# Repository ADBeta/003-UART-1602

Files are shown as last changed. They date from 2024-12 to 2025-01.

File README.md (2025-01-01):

# 003-UART-1602
UART/RS232 Enabled controller for a basic `1602 Monochrome LCD`, in 4-bit mode
using the `CH32V003 - TSSOP-20` MCU  
Features:
* Selectable Baudrate
* Backlight Control using UART or Hardware override
* 4-bit LCD Control protocol support
* Automatic Line Scroll
* Operation down to 2.7v
* LCD Contrast Charge Pump
* Advance Display Control over UART

<div style="display: flex; align-items: center; gap: 10px;">
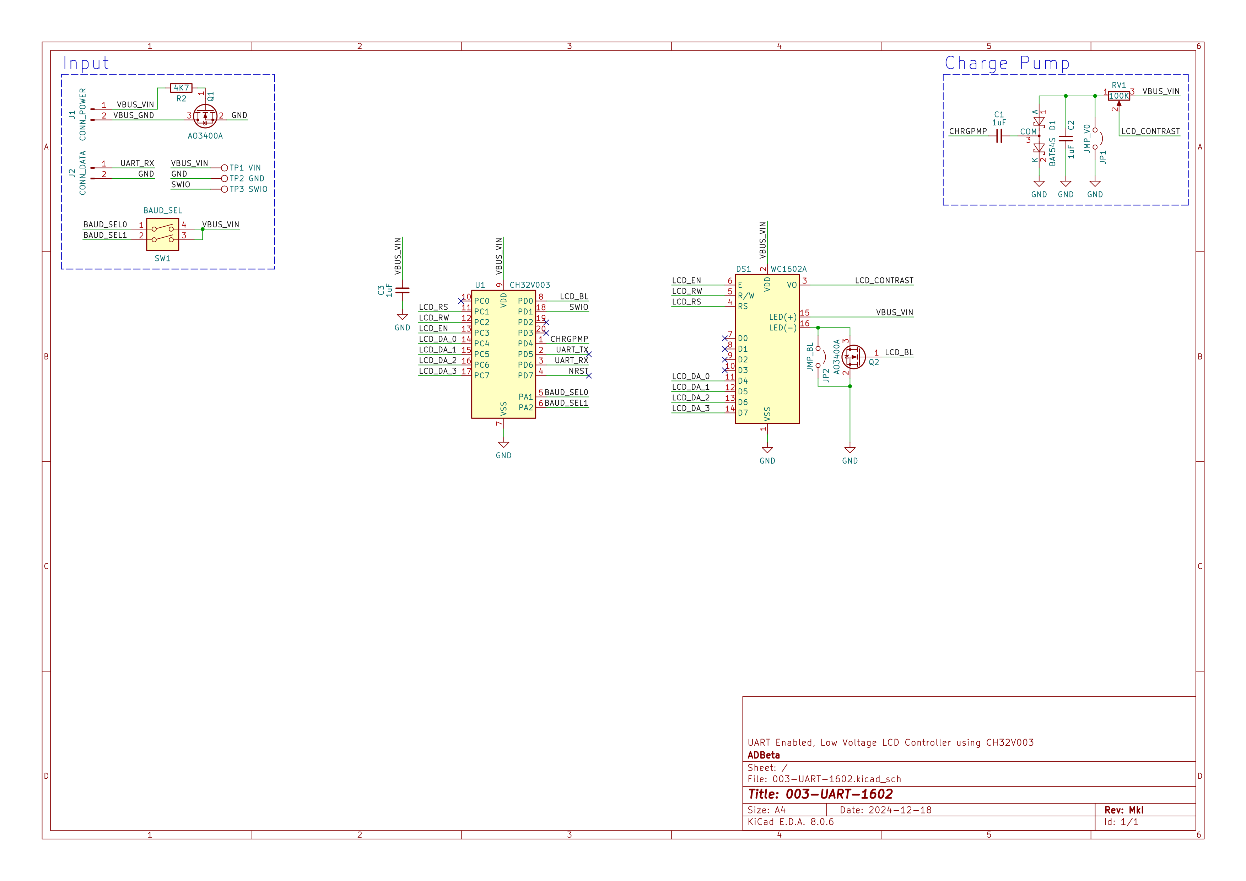
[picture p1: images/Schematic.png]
Schematic
  <br>
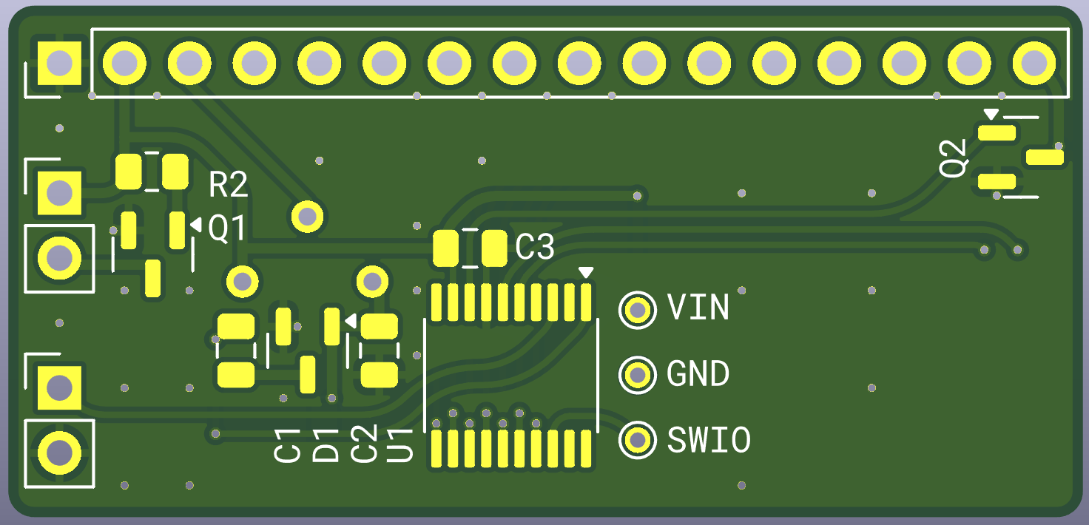
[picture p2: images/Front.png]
PCB_Front
  
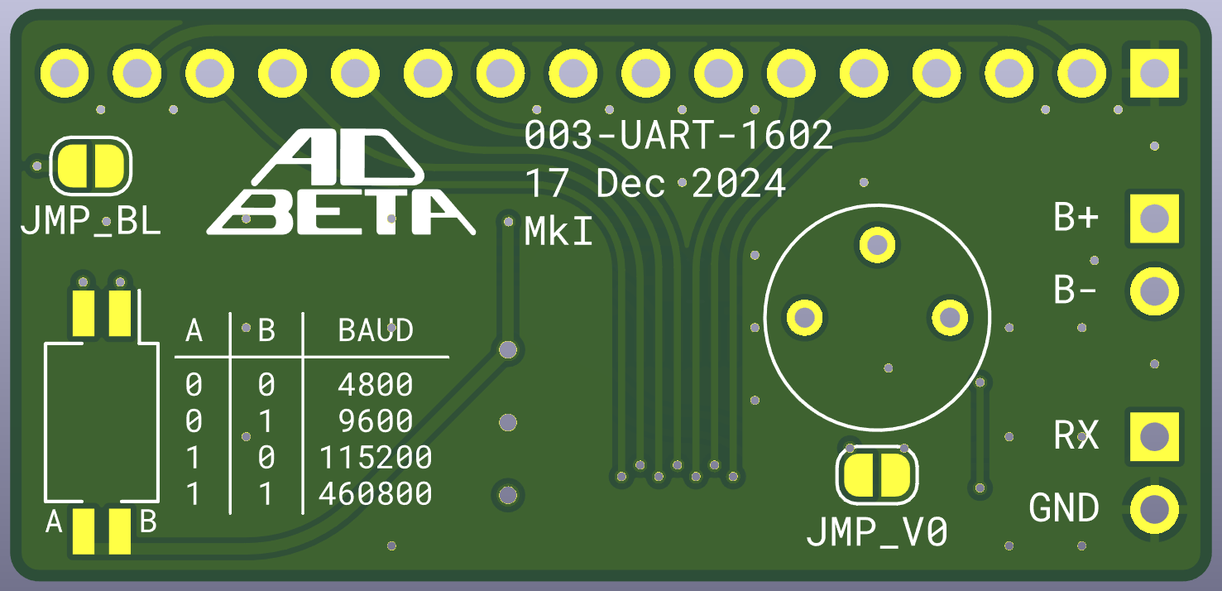
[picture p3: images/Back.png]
PCB_Back
  
</div>

## Display Operation
The display will read any incoming UART or RS232 Data and print it to the 
screen in realtime - If the edge of the screen is exceeded, the display will
drop incoming data.  
When `Line Feed` is received, and the Display is already on `Line 2`, the display
will Scroll Down, so the line being printed to remains as `Line 2`  

See [Control Characters](#control-characters) for a list of control commands
that can be used for the display

## Startup Conditions
When the Display is powered on, and before it receives any UART data, the
device is in the following state:
* LCB Backlight OFF
* Display Configured and blanked

## Selectable Baudrate
Receiver Baudrate is selected via the DIP-Switches onboard.  
The setting is checked once a second so the setting can be 
changed on the fly.  
```
B1 B0  Baud
0  0   4800
0  1   9600
1  0   115200
1  1   460800
```

## Low Voltage Operation
There is a negative charge pump onboard that provides a near-rail negative
voltage, that is fed to one end of the contrast selection Potentiometer.  
These LCDs are only officially rated at 5v, so use lower voltages 
**AT  YOUR OWN RISK**.  
To disable the charge pump, do not populate the components, and short
the `JMP_V0` Jumper.  
The `Minimum Voltage` for the unit is 2.7v

## Control Characters
`BELL    0x07` - Flashes the Backlight quickly for 3 Seconds  
`LF      0x0A` - Feeds line down, keeping Column Position  
`CR      0x0D` - Returns to the First Column on the current line  
`DC1     0x11` - Device Control 1, Turns Backlight On  
`DC2     0x12` - Device Control 2, Turns Backlight Off  
`DC3     0x13` -   
`DC4     0x14` -  
`ESCAPE  0x1B` - Clears the Screen and returns to position 0,0  

Any Control Characters not mentioned above will be ignored.

## Pinout
```
PA1  Baud Select 1
PA2  Baud Select 2

PC0  ---
PC1  LCD_RS  Register Select
PC2  LCD_RW  Read/Write
PC3  LCD_EN  Enable
PC4  LCD_D4  Display Data Pin 4
PC5  LCD_D5  Display Data Pin 5
PC6  LCD_D6  Display Data Pin 6
PC7  LCD_D7  Display Data Pin 7

PD0  Backlight Control
PD1  !!Reserved for SWIO!!
PD2  --
PD3  --
PD4  Charge Pump PWM
PD5  TX  UART Transmit (Not Connected)
PD6  RX  UART Receive
PD7  Reserved for NRST
```

## MkII PCB Partslist
```
C1    0603 1uF 10V
C2    0603 1uF 10V
C3    0603 1uF 10V
R1    0603 4K7
R2    100K 5mm x 5mm Potentiometer
D1    BAT54S
Q1    AO3401 P-Ch
Q2    A03400 N-Ch
U1    CH32V003
SW1   1.27mm 2P DIP Switch
```

## TODO
* Device Contol 3 and 4 Behaviour

----
ADBeta (c) 2024 - 2025

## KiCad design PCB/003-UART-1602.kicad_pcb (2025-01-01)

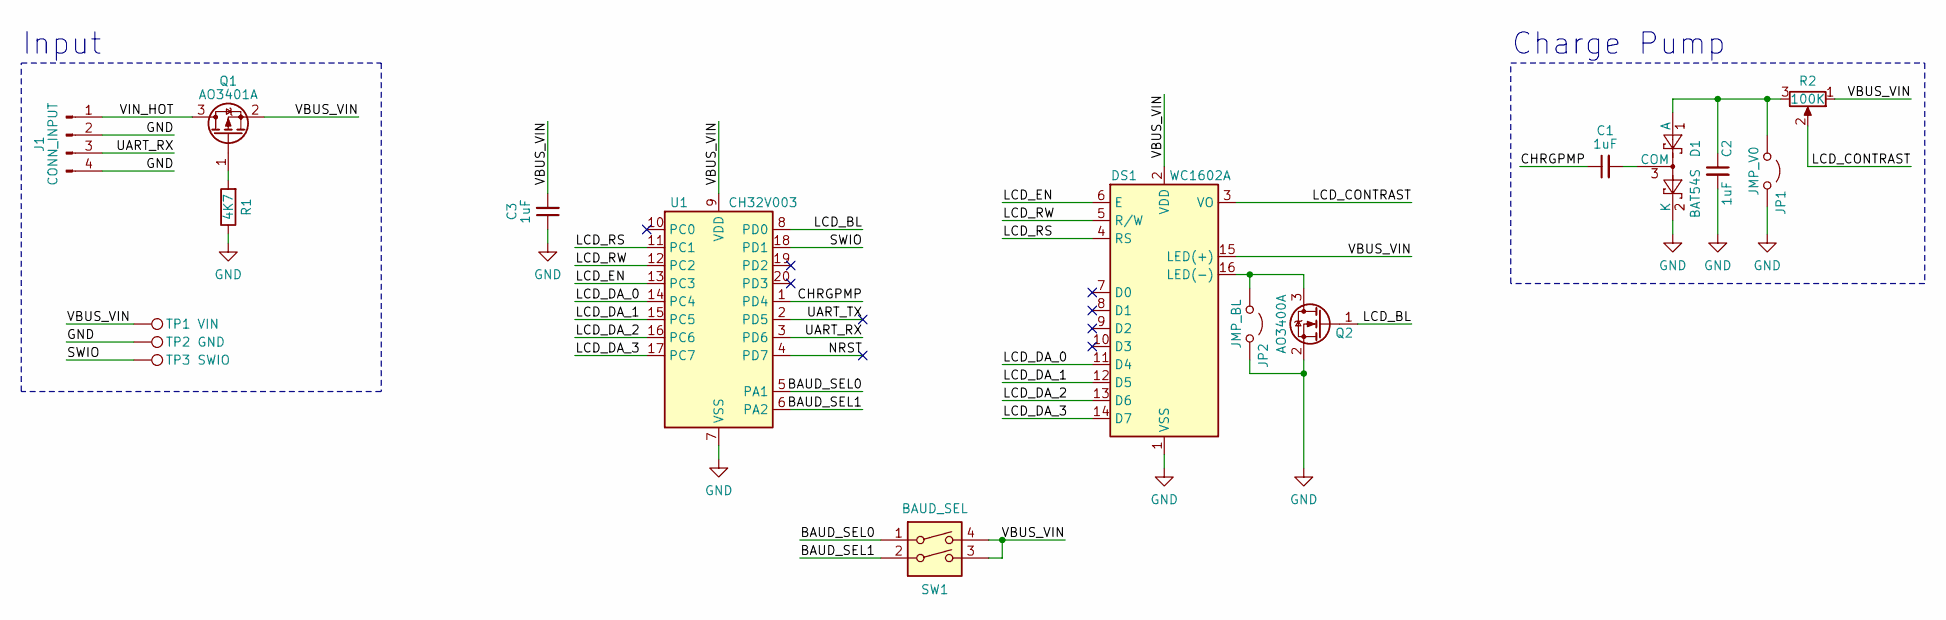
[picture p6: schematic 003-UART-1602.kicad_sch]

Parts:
C1, C2, C3: 1uF; C_0805_2012Metric
D1: BAT54S; SOT-23
DS1: WC1602A; PinHeader_1x16_P2.54mm_Vertical
J1: CONN_INPUT; PinHeader_1x04_P2.54mm_Vertical
JP1: JMP_V0; SolderJumper-2_P1.3mm_Open_RoundedPad1.0x1.5mm
JP2: JMP_BL; SolderJumper-2_P1.3mm_Open_RoundedPad1.0x1.5mm
Q1: AO3401A; SOT-23
Q2: AO3400A; SOT-23
R1: 4K7; R_0805_2012Metric
R2: 100K; Potentiometer_Piher_PT-6-V_Vertical
SW1: BAUD_SEL; SW_DIP_SPSTx02_Slide_Copal_CHS-02B_W7.62mm_P1.27mm
TP1: VIN; TestPoint_Pad_D1.0mm
TP2: GND; TestPoint_Pad_D1.0mm
TP3: SWIO; TestPoint_Pad_D1.0mm
U1: CH32V003; TSSOP-20_4.4x6.5mm_P0.65mm

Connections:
/BAUD_SEL0: SW1.1, U1.5 (PA1)
/BAUD_SEL1: SW1.2, U1.6 (PA2)
/CHRGPMP: C1.1, U1.1 (PD4)
/LCD_BL: Q2.1 (G), U1.8 (PD0)
/LCD_CONTRAST: DS1.3 (VO), R2.2
/LCD_DA_0: DS1.11 (D4), U1.14 (PC4)
/LCD_DA_1: DS1.12 (D5), U1.15 (PC5)
/LCD_DA_2: DS1.13 (D6), U1.16 (PC6)
/LCD_DA_3: DS1.14 (D7), U1.17 (PC7)
/LCD_EN: DS1.6 (E), U1.13 (PC3)
/LCD_RS: DS1.4 (RS), U1.11 (PC1)
/LCD_RW: DS1.5 (R/W), U1.12 (PC2)
/NRST: U1.4 (PD7)
/SWIO: TP3.1, U1.18 (PD1)
/UART_RX: J1.3, U1.3 (PD6)
/UART_TX: U1.2 (PD5)
/VBUS_VIN: C3.2, DS1.2 (VDD), DS1.15 (LED(+)), Q1.2 (S), R2.1, SW1.3, SW1.4, TP1.1, U1.9 (VDD)
/VIN_HOT: J1.1, Q1.3 (D)
GND: C2.2, C3.1, D1.2 (K), DS1.1 (VSS), J1.2, J1.4, JP1.1 (A), JP2.1 (A), Q2.2 (S), R1.1, TP2.1, U1.7 (VSS)
unnamed: C2.1, D1.1 (A), JP1.2 (B), R2.3
unnamed: C1.2, D1.3 (COM)
unnamed: DS1.16 (LED(-)), JP2.2 (B), Q2.3 (D)
unnamed: Q1.1 (G), R1.2

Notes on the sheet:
Charge Pump
Input

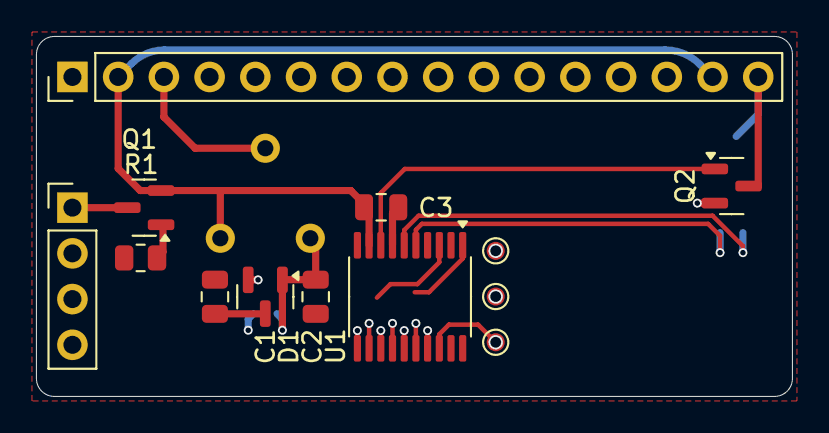
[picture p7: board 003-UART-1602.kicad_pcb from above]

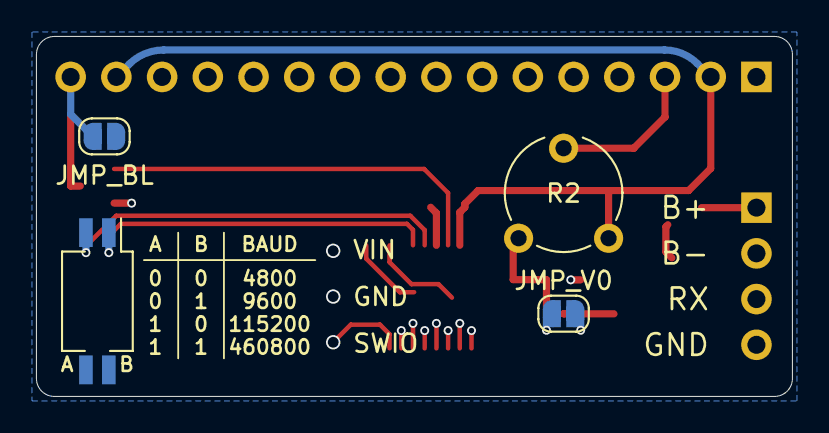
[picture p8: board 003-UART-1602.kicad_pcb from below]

Board: 2 copper layers, 42.0 x 20.0 mm, 17 parts (4 on the bottom side), 21 nets.

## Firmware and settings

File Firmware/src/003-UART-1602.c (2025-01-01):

/******************************************************************************
* 003-UART-1602
* A UART Enabled Controller for a basic 1602 Monochrome LCD
* For more information see the GitHub: 
* https://github.com/ADBeta/003-UART-1602
*
* Ver 1.4    01 Jan 2025
* ADBeta (c) 2024 - 2025
******************************************************************************/
#include "ch32v003fun.h"
#include "lib_gpioctrl.h"
#include "lib_uart.h"
#include "lib_lcd1602.h"

/*** Pin Definitions *********************************************************/
#define PUMP_PWM     GPIO_PD4
#define LCD_BL       GPIO_PD0
#define BAUD_SEL0    GPIO_PA1
#define BAUD_SEL1    GPIO_PA2

/*** Macros ******************************************************************/
#define SYSTICK_ONE_MILLISECOND ((uint32_t)FUNCONF_SYSTEM_CORE_CLOCK / 1000)
#define SYSTICK_ONE_MICROSECOND ((uint32_t)FUNCONF_SYSTEM_CORE_CLOCK / 1000000)
#define millis() (g_systick_millis)
#define micros() (SysTick->CNT / SYSTICK_ONE_MICROSECOND)

/*** Enums and Structs *******************************************************/
typedef enum {
	LED_OFF       = 1,
	LED_ON        = 2,
	LED_BLINK     = 3
} led_mode_t;


/*** Globals *****************************************************************/
//// UART ////
// UART Ring Buffer and Receive buffer
#define UART_BUFFER_SIZE 128
static uint8_t g_uart_buffer[UART_BUFFER_SIZE] = {0x00};
static uint8_t g_recv_buffer[UART_BUFFER_SIZE] = {0x00};

// Baudrate lookup table
static uart_baudrate_t g_baud_lookup[4] = { 
	UART_BAUD_4800, UART_BAUD_9600, UART_BAUD_115200, UART_BAUD_460800 
};

// Create a UART Configuration 
static uart_config_t g_uart_conf = {
	.baudrate    = UART_BAUD_4800,
	.wordlength  = UART_WORDLENGTH_8,
	.parity      = UART_PARITY_NONE,
	.stopbits    = UART_STOPBITS_ONE,
	.flowctrl    = UART_FLOWCTRL_NONE,
};

//// LCD ////
#define LCD_LINE_MAX_CHARS 16

// Create LCD Device
static lcd_device_t g_lcd_dev = {
	.LCD_RS      = GPIO_PC1,
	.LCD_RW      = GPIO_PC2,
	.LCD_EN      = GPIO_PC3,
	.LCD_DA      = {GPIO_PC4, GPIO_PC5, GPIO_PC6, GPIO_PC7},
};

lcd_position_t g_lcd_pos = {0, 0};

// When a BELL is received, blink a set number of times.
led_mode_t g_led_mode =   LED_OFF;
uint32_t   g_led_blinks = 0;


//// Timing ////
// Incremented in the SysTick IRQ once per millisecond
volatile uint32_t g_systick_millis;

#define BAUD_UPDATE_MS   1000
#define DISP_UPDATE_MS     50
#define LIGHT_UPDATE_MS   100

static uint32_t g_last_baud_update_millis    = 0;
static uint32_t g_last_disp_update_millis    = 0;
static uint32_t g_last_light_update_millis   = 0;


/*** Forward Declaration *****************************************************/
/// @brief Initialise the SysTick interrupt to incriment every 1 millisecond
/// @param None
/// @return None
static void systick_init(void);

/// @brief SysTick IRQ
/// @param none
/// @return none
__attribute__((interrupt))
void SysTick_Handler(void);

/// @brief Initialises PWM on Timer2,         NOTE: PD4 in this case
/// @param None
/// @return None
void pwm_init(void);

/// @brief Sets the Duty Cycle PWM output
/// @param duty, 0 - 255
/// @return None
__attribute__((always_inline))
inline void pwm_set_duty(const uint32_t duty);

/// @brief returns if the given char is a printable char
/// @param char input
/// @return bool result
__attribute__((always_inline))
inline bool is_printable(const char input) {
	if(input >= 0x20) return true;
	return false;
}



/*** Main ********************************************************************/
int main(void)
{	
	/*** Init ***/
	SystemInit();

	// Backlight is output, turn off by default
	gpio_set_mode(LCD_BL, OUTPUT_10MHZ_PP);
	gpio_digital_write(LCD_BL, GPIO_LOW);
	// Selection Switches are input
	gpio_set_mode(BAUD_SEL0, INPUT_PULLDOWN);
	gpio_set_mode(BAUD_SEL1, INPUT_PULLDOWN);
	// Charge Pump is output in alternate function mode for PWM
	gpio_set_mode(PUMP_PWM, OUTPUT_10MHZ_PP | OUTPUT_PP_AF);

	// Wait for power to settle then init LCD
	Delay_Ms(250);
	lcd_init(&g_lcd_dev);

	// Start the PWM on PD4: 50% Duty, 9.9KHz
	pwm_init();
	pwm_set_duty(127);

	// Enable the systick for timing update and read of user settings
	systick_init();
	
	// Initialise the UART driver, will start populating ring buffer
	uart_init(g_uart_buffer, UART_BUFFER_SIZE, &g_uart_conf);



	/*** Main Loop ***/
	while(true)
	{
		/*** Baudrate Selection Switch ***/
		if(g_systick_millis - g_last_baud_update_millis > BAUD_UPDATE_MS)
		{
			// Get the current Baud Setting selection
			uint8_t baud_setting = 
				((uint8_t)gpio_digital_read(BAUD_SEL1)) << 1 |
				 (uint8_t)gpio_digital_read(BAUD_SEL0);

			// Set the Baudrate register
			USART1->BRR = g_baud_lookup[baud_setting];

			// Reset for the next baudrate update
			g_last_baud_update_millis = g_systick_millis;
		} // End of Baudrate Selection



		/*** UART Data Parsing ***/
		if(g_systick_millis - g_last_disp_update_millis > DISP_UPDATE_MS)
		{
			// Read any bytes availabe in the buffer, then parse it 
			size_t recv_chars = uart_read(g_recv_buffer, UART_BUFFER_SIZE);

			// Go through every received char to parse it
			for(uint8_t index = 0; index < recv_chars; index++)
			{
				char c_char = g_recv_buffer[index];
				

				// Print only Printable characters
				if(is_printable(c_char))
				{
					// Get the current position, only print if below x[16]
					g_lcd_pos = lcd_get_pos(&g_lcd_dev);
					if(g_lcd_pos.x < 16) 
						lcd_send_char(&g_lcd_dev, c_char);

				// If it is a control char, parse it
				} else {
					switch(c_char)
					{
						// BELL
						case 0x07:
							g_led_mode = LED_BLINK;
							g_led_blinks = 20;
							break;

						// LINE FEED
						// Moves down one line, keeping carriage position.
						// If on line 2, move display info up to line 1
						case 0x0A:
							// Get the current position, if on the 1st line, move down
							g_lcd_pos = lcd_get_pos(&g_lcd_dev);
							if(g_lcd_pos.y == 0)
							{
								g_lcd_pos.y = 1;
								lcd_set_pos(&g_lcd_dev, g_lcd_pos);
							
							// If it's on the second line...
							} else {
								// Copy line 2 data to buffer
								char line_str[17] = {0x00};
								lcd_set_pos(&g_lcd_dev, (lcd_position_t){0,1});
								lcd_read_string(&g_lcd_dev, line_str, 16);

								// Clear display - resets to 0,0
								// write line 2 data to line 1
								lcd_send_cmd(&g_lcd_dev, 0x01);
								lcd_send_string(&g_lcd_dev, line_str);

								// Set the position to where it was
								lcd_set_pos(&g_lcd_dev, g_lcd_pos);
							}							
							break;

						// CARRIAGE RETURN
						// Sets cursor position to char 0 of the current line
						case 0x0D:
							g_lcd_pos = lcd_get_pos(&g_lcd_dev);
							g_lcd_pos.x = 0;
							lcd_set_pos(&g_lcd_dev, g_lcd_pos);
							break;

						// DEVICE CONTROL 1
						// Backlight ON
						case 0x11:
							g_led_mode = LED_ON;
							g_led_blinks = 0;
							break;

						// DEVICE CONTROL 2
						// Backlight OFF
						case 0x12:
							g_led_mode = LED_OFF;
							g_led_blinks = 0;
							break;
					
						// DEVICE CONTROL 3
						// TBD
						case 0x13:
							break;
					
						// DEVICE CONTROL 4
						// TBD
						case 0x14:
							break;

						// ESCAPE
						// Clears the display and returns to 0
						case 0x1B:
							lcd_send_cmd(&g_lcd_dev, 0x01);
							break;

						default:
							break;
					}
				}
			}


			// Reset timer for next UART Data Update
			g_last_disp_update_millis = g_systick_millis;
		} // End of Character Parsing



		if(g_systick_millis - g_last_light_update_millis > LIGHT_UPDATE_MS)
		{
			static led_mode_t last_mode = LED_OFF;
			static GPIO_STATE last_state = GPIO_LOW;


			switch(g_led_mode)
			{
				case LED_OFF:
					gpio_digital_write(LCD_BL, GPIO_LOW);
					last_mode =   LED_OFF;
					last_state =  GPIO_LOW;
					break;

				case LED_ON:
					gpio_digital_write(LCD_BL, GPIO_HIGH);
					last_mode =   LED_ON;
					last_state =  GPIO_HIGH;
					break;

				case LED_BLINK:
					// Reset when done blinking
					if(g_led_blinks-- == 0) g_led_mode = last_mode;
					// Toggle the LED
					gpio_digital_write(LCD_BL, (last_state = !last_state));
					
					break;
				

				default:
					break;
			}

			g_last_light_update_millis = g_systick_millis;
		} // End of Backlight Update

	} // End of loop
} // End of main()




/*** Functions ***************************************************************/
static void systick_init(void)
{
	// Reset any pre-existing configuration
	SysTick->CTLR = 0x0000;
	
	// Set the compare register to trigger once per millisecond
	SysTick->CMP = SYSTICK_ONE_MILLISECOND - 1;

	// Reset the Count Register, and the global millis counter to 0
	SysTick->CNT = 0x00000000;
	g_systick_millis = 0x00000000;
	
	// Set the SysTick Configuration
	// NOTE: By not setting SYSTICK_CTLR_STRE, we maintain compatibility with
	// busywait delay funtions used by ch32v003_fun.
	SysTick->CTLR |= SYSTICK_CTLR_STE   |  // Enable Counter
	                 SYSTICK_CTLR_STIE  |  // Enable Interrupts
	                 SYSTICK_CTLR_STCLK ;  // Set Clock Source to HCLK/1
	
	// Enable the SysTick IRQ
	NVIC_EnableIRQ(SysTicK_IRQn);
}


__attribute__((interrupt))
void SysTick_Handler(void)
{
	// Increment the Compare Register for the next trigger
	SysTick->CMP += SYSTICK_ONE_MILLISECOND;

	// Clear the trigger state for the next IRQ
	SysTick->SR = 0x00000000;

	// Increment the milliseconds count
	g_systick_millis++;
}


void pwm_init(void)
{
	// NOTE: Uses TIM2 Channel 1 (PD0) as the PWM Output pin
	// Change CHCTLR1 to CHCTLR2 for CH3 or CH4

	// Enable TIM2 Clock
	RCC->APB1PCENR |= RCC_APB1Periph_TIM2;
	
	// Reset TIM2, Inits all registers
	RCC->APB1PRSTR |= RCC_APB1Periph_TIM2;
	RCC->APB1PRSTR &= ~RCC_APB1Periph_TIM2;

	// Set Prescaler (9.9kHz)
	TIM2->PSC = 0x0012;
	// Set PWM Max Value (Autoreload Value)
	TIM2->ATRLR = 254;

	// Set the Compare Capture Register for Channel 1
	// TIM2_OC1M = 0b111 - PWM Mode 2 - Enable Preload
	TIM2->CHCTLR1 |= TIM_OC1M_2 | TIM_OC1M_1 | TIM_OC1M_0 | TIM_OC1PE;

	// Enable auto-reload
	TIM2->CTLR1 |= TIM_ARPE;

	// Enable channel output, set polarity ACTIVE_LOW
	TIM2->CCER |= TIM_CC1E | TIM_CC1P;

	// Initialise Counter
	TIM2->SWEVGR |= TIM_UG;

	// Enable TIM2
	TIM2->CTLR1 |= TIM_CEN;
}


__attribute__((always_inline))
inline void pwm_set_duty(const uint32_t duty)
{
	// NOTE: Channel 1, change CHxCVR for channel selection
	TIM2->CH1CVR = duty;
}

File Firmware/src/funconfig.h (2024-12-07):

#ifndef _FUNCONFIG_H
#define _FUNCONFIG_H

#define CH32V003                 1

// Enable/Disable overwriting of the RX Ring Buffer.
// Enabled:  Incomming data will overwrite older data in the buffer
// Disabled: Incomming data will not be added to the buffer until space is free
#define RX_RING_BUFFER_OVERWRITE

// NOTE: UART_ALTERNATE_1 will disable SWIO (PD1)
//  Pinout        TX        RX        CTS        RTS
//  Default       PD5       PD6       PD3        PC2
//  Alternate 1   PD0       PD1       PC3        PC2
//  Alternate 2   PD6       PD5       PC6        PC7
//  Alternate 3   PC0       PC1       PC6        PC7
#define UART_PINOUT_DEFAULT

#endif

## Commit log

2024-12-07 Added Basic UART Control
2024-12-07 Updated UART Code
2024-12-09 Added BAUD Setting detection
    [UART_LCD_MkI.kicad_sch]
2024-12-10 Added reverse protection to test & connectors
    [UART_LCD_MkI.kicad_sch]
2024-12-11 Changed parsing flow
2024-12-12 Fixed baud detection - Added Read CHAR from LCD Memory
    [UART_LCD.c, lib_lcd1602.c]
2024-12-12 Updated PCB
    [UART_LCD_MkI.kicad_pcb, UART_LCD_MkI.kicad_sch]
2024-12-16 PCB Progress
    [UART_LCD_MkI.kicad_pcb, UART_LCD_MkI.kicad_sch]
2024-12-16 Changed Project Name
    [003-UART-1602.kicad_pcb, 003-UART-1602.kicad_sch]
2024-12-17 Added DIP Switch to PCB
    [003-UART-1602.kicad_pcb, 003-UART-1602.kicad_sch]
2024-12-17 Almost Final PCB
    [003-UART-1602-B_Cu.gbr, 003-UART-1602-B_Mask.gbr, 003-UART-1602-B_Paste.gbr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]
2024-12-18 PCB Finished
    [003-UART-1602-B_Cu.gbr, 003-UART-1602-B_Mask.gbr, 003-UART-1602-B_Paste.gbr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]
2024-12-18 Added Images
    [003-UART-1602-B_Cu.gbr, 003-UART-1602-B_Mask.gbr, 003-UART-1602-B_Paste.gbr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]
2024-12-18 Changed Image sizes
    [003-UART-1602.kicad_pcb]
2024-12-30 MkII PCB Notes
2025-01-01 MkII PCB Design started
    [003-UART-1602.kicad_pcb, 003-UART-1602.kicad_sch]
